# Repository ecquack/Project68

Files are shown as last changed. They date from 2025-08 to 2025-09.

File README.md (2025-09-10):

# Project68

Project68 is a Motorola MC68xxx 16/32 bit single board computer with an 8 bit PIC18 co-processor. 

My goal was to do something interesting with the tube of factory new 68008 CPUs that I've been hoarding for 25 years, 
so I have designed a useful self contained 68K computer using a minumum number of components and special tools.

The system connects directly to a monitor and keyboard and does not require a host computer.

This project is at an early stage of development, but it is intended to run uCLinux 4.4.

Special thanks to [*crmaykish*](https://github.com/crmaykish), creator of the [Mackerel-68K](https://github.com/crmaykish/mackerel-68k) project.

## Project68 features

- MC68008FN8 CPU clocked at 7.16 mHz
- 4 megabytes of SRAM
- Optional overclocking to 14.31818 mHz
- PIC18F87J11 co-processor clocked at 14.31818 mHz (57.27 mHz internal w/4X PLL)
- 80x25 character monochrome ASCII video display (NTSC composite video)
- PS/2 keyboard interface
- TTL/USB serial port
- micro-SD card socket
- Audio Speaker for ASCII “bell” sound
- **No PAL/GAL/CPLD/FPGA programmable logic required**
- Only two LVTTL parts required.
- Expansion ports for a dual serial card and a non-volatile RTC

## OPERATING REQUIREMENTS

- TV or Monitor with composite video input (NTSC)
- PS/2 keyboard
- 5V 1A power supply with USB-C cable (phone charger)
- SD card with uCLinux image

## CPU

The CPU is the 8 bit external bus version of the 68K, the MC68008FN8. It comes in the larger 52 pin PLCC package which can address up to 4 megabytes of memory. The CPU is socketed on the board so that you can use an automated assembly service such as JLC PCB or PCBWAY for all the soldering if you prefer. This is a 16/32 bit CPU internally with a narrow external bus which allows using byte wide external memories.

The parts I have are rated at 8mHz, but 10mHz parts are also available (MC68000FN10). In order to provide an NTSC video clock, the processor runs at ~7.16mHz. Either speed part can (usually) be successfully overclocked to ~14.318mHz without issue. An overclocking jumper is provided if you feel the need for speed.

## MEMORY

The system has four megabytes of memory. It uses a single 32 megabit 4Mx8 55ns SRAM chip. This fills the *entire* available address space with SRAM. There is no separate FLASH, EPROM, or ROM memory, no address decoding of any kind,  no special address hardware at reset, and no traditional memory mapped I/O. Just an unbroken sea of RAM from 0-0x3FFFFF and a simple _DTACK generator. 

The SRAM part is a fairly pricey Renesas RMLV3216AGSA-5S2 sourced from Digikey. You can also use the pin compatible Alliance AS6C6416-55TIN from Mouser which is a 64 megabit part, which is actually cheaper, but you will only be utilizing half the memory.

The memory and the PIC18 run at 3.3 volts (there is an LDO regulator on the board). The 5 volt MC68008  has a logic high level of 2.4 volts, which might be safe to use with these parts. I may end up using level shifters, but they eat 20 nanoseconds from the bus cycle. Stay tuned for my experimental results.

## CO-PROCESSSOR

The PIC18F87J11 microcontroller comes in an 80 pin TQFP package. This part was chosen because it has enough GPIO pins to emulate the entire MC68008 bus. It has 128K of FLASH memory, and just under 4K of on chip SRAM.

**The PIC18 co-processor provides all the main processor’s I/O using soft-DMA.** When it is time to transfer data to or from the processor, the co-processor requests the bus from the 68008. When the bus is granted, it uses bit-banging DMA to read and write the SRAM. A few specific addresses in the memory space are designated as I/O command and status registers and are interpreted as such by the co-processor to provide low level BIOS functions for the console, serial port, and SD card. 

At power up the co-processor asserts _HALT and _RESET and then copies up to 64K of BIOS into the SRAM from the upper half of FLASH memory that’s built into the PIC18. It then releases the 68K bus and the MC68008 starts.

## VIDEO DISPLAY

**The co-processor is also responsible for generating the 80x25 video display.** This is done with a *really* tight  horizontal sync interrupt handler written in assembly language. It uses an interleaved character FLASH lookup table with an 8x8 pixel font. One EUSART on the PIC18 is used as a video shift register (nice!), which makes it possible to clock pixels out once per instruction cycle.

Roughly half of the PIC18's SRAM (2K) is dedicated to the video display.

The physical video interface consists of two output pins and a two resistor network that is connected to an RCA jack. One pin is the output of the synchronous serial transmitter, and the other is the software generated sync line, used for both horizontal and vertical sync.

The video display is not interlaced and does not include a colorburst. The 8x8 ROM font consists of the standard printable ASCII characters (codes 32-126), plus a number of special characters (codes 0-31 and 127). The upper 128 characters are reverse video of the lower 128 characters, which is used to generate the cursor. There are no fancy effects like blink, underscore, or dim. There are no code page 437 special characters.

Most of the co-processor's time is spent generating video. There is a short horizontal blanking period at the end of each line, and there is a longer vertical blanking interval at the end of each video field during which the processor is free to perform other tasks. All video generation (and PS/2 keyboard processing) takes place inside the interrupt handler.

Note that it should be possible to run a PAL monitor instead of NTSC by simply adjusting the timing #DEFINE statements in the beginning of *80columnvideo.h*.
I do not have a monitor that accepts PAL video to test this with.

## PS/2 INTERFACE

The system uses the PIC18 MSSP (synchronous serial port) in slave mode with an assembly language interrupt handler to interface to the PS/2 keyboard. 
The interrupt handler runs during horizontal blanking, and always takes the same number of clock cycles to run, no matter which code path is taken, to avoid disturbing the video output. 

When characters arrive on the PS/2 keyboard or serial port, the co-processor requests the bus, and stores the received characters into a software FIFO in SRAM.

## SD CARD

The SD card socket is connected to the PIC18 over the shared SPI bus. 512 bytes of PIC18 SRAM is reserved to store a single block of data to/from the SD card. 

## BIOS

The BIOS provides a few functions to access the console, the serial port, and the SD card. It also loads and starts Linux from the SD card. Additional functions could be added, for example, to copy the entire screen buffer to and from memory, give control over the PWM audio output beyond the fixed "beep", or to support additional SPI devices such as a non-volatile real time clock. 

## TIMER INTERRUPT

The vertical blanking signal serves as a periodic timer interrupt (60 hertz) to the 68008. This is used by the BIOS for communication and by the Linux kernel for timekeeping and task switching. 

## USB/TTL SERIAL PORT

A CH340N provides a very basic serial port connection to a USB host system. The USB C connector also provides power to the board. There is also a header with jumpers that allow the TTL serial lines to be disconnected from the USB chip and used directly. 

## EXPANSION PORTS

There are two main expansion ports. Each has power, SPI bus, it's own SPI chip select, it's own interrupt line, and two GPIO pins. My intention is to use an SPI DUAL UART on one port and an SPI RTC on the other. Supporting these will require additions to the BIOS. The interrupt line and the chip select can be used as GPIOs if the SPI bus is not used, but MISO, MOSI, and SCLK are shared with the SD card socket and cannot be reassigned.

There is also a third expansion port which brings out the three unused PIC18 GPIO pins, power, and ground. Two of these pins are on port B and can be used as interrupt sources.

## ICSP PORT

For programming the PIC MCU, this 6 pin connector contains PGD, PGC, _MCLR, +5V, and GND.

## PERFORMANCE NOTES

The current system was designed to see how simply a complete 68K computer system could be made, and it uses a minimum number of parts for a system that has its own video and keyboard interfaces. By adding just a few chips you can dramatically increase the performance of the system.

For higher overall system performance you could use a second smaller PIC18 (such as a PIC18F26K22) dedicated to generating video. Right now there is an I/O bottleneck because I/O operations are only performed during video blanking.

A decoded address that causes an interrupt on the PIC18 would eliminate the need for the PIC18 to poll the MC68008's memory. Again, this would increase performance but it would add chips to the design and eat into the memory address space. Two 74HCT30s and a 74HCT00 would suffice, and would eat only 64 bytes from the memory map. 

## BUILD REQUIREMENTS
 
- PIC programmer for initial programming (you can build a very simple bit-banging programmer using a repurposed Arduino)
- Computer system with MicroSD card interface for preparing the SD card.
- CCS PICC C Compiler (optional - pre-built binaries are available)*
- X86 Linux system (optional - a pre-built binary is available)
- KiCAD (optional - Gerber files are provided)

*note that there is a 45 day free trial of this compiler.

## Pre-assembled boards

I started out with a tube full of sixteen 68008 parts that I got from a Motorola rep back in the '90s. I'm keeping a few chips for myself and my friends, but 
I may have a few pre-assembled boards complete with CPUs and SD cards for sale at some point. 

Note that the MC68008FN is no longer in production, but at this time (August, 2025) it is not difficult to find them on eBay for around USD$30 with shipping. 

## PROJECT STATUS

The schematic capture and layout of the first version is complete. I'll order the blank boards and stencil from JLCPCB next.

I wrote the PIC18 80 column video code and the PS/2 keyboard handler code back in 2010 and posted them to the CCS C compiler forum. They were tested on a single sided PIC18F26J11 board that I milled on my CNC machine back in the day.

Once the layout is complete I plan to have a pair of assembled boards made for my by JLCPCB.

After that, the next debugging steps are:

0. Blink the LED
1. Get the video display running
2. test the keyboard port
3. bit-bang the memory interface to read and write from the SRAM
4. load a small test program into the 68K and start it
5. read and write a block from the SD card

Then comes the work of writing the BIOS and building the linux image.

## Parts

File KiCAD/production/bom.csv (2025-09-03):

Designator | Footprint | Quantity | Value | LCSC Part #
BZ1 | MURATA | 1 | Buzzer
C2 | 1206 | 1 | 10uF tantalum
D1 | 1206 | 1 | LED
IC1 | PLCC52-S | 1 | MC68008FN
J1 | CUI_RCJ-044 | 1 | RCJ-044
J10 | PinHeader_1x10_P2.54mm_Vertical | 1 | RTC_OPTION
J11 | PinHeader_1x10_P2.54mm_Vertical | 1 | SERIAL_OPTION
J2 | CUI_MD-60S | 1 | MD-60S
J3 | microSD_HC_Molex_47219-2001 | 1 | Micro_SD_Card
J4 | PinHeader_1x03_P2.54mm_Vertical | 1 | Overclock jumper
J5 | USB_C_Receptacle_GCT_USB4105-xx-A_16P_TopMnt_Horizontal | 1 | USB_C_Receptacle_USB2.0_14P
J6 | PinHeader_1x02_P2.54mm_Vertical | 1 | POWER INPUT
J8 | PinHeader_1x08_P2.54mm_Vertical | 1 | Conn_01x08_Pin
J9 | PinHeader_1x06_P2.54mm_Vertical | 1 | ICSP
Q1 | SOT-23-3 | 1 | NPN
R1 | 1206 | 1 | 330
R10, R3, R9 | 1206 | 3 | 1K
R2 | 1206 | 1 | 680
R4, R5, R6, R7 | 1206 | 4 | 5K1
R8 | 1206 | 1 | 220
U11 | QFP50P1400X1400X120-80N | 1 | PIC18F87J11T-I_PT
U2 | TSOP-I-48_18.4x12mm_P0.5mm | 1 | ~
U3 | SOIC-14_3.9x8.7mm_P1.27mm | 1 | 74LV00
U4 | SOIC-14_3.9x8.7mm_P1.27mm | 1 | 74LV74
U5 | SOT-223-3_TabPin2 | 1 | AMS1117-3.3
U6 | SOP-8_3.9x4.9mm_P1.27mm | 1 | CH340N
Y1 | Oscillator_DIP-14 | 1 | OCXO-14

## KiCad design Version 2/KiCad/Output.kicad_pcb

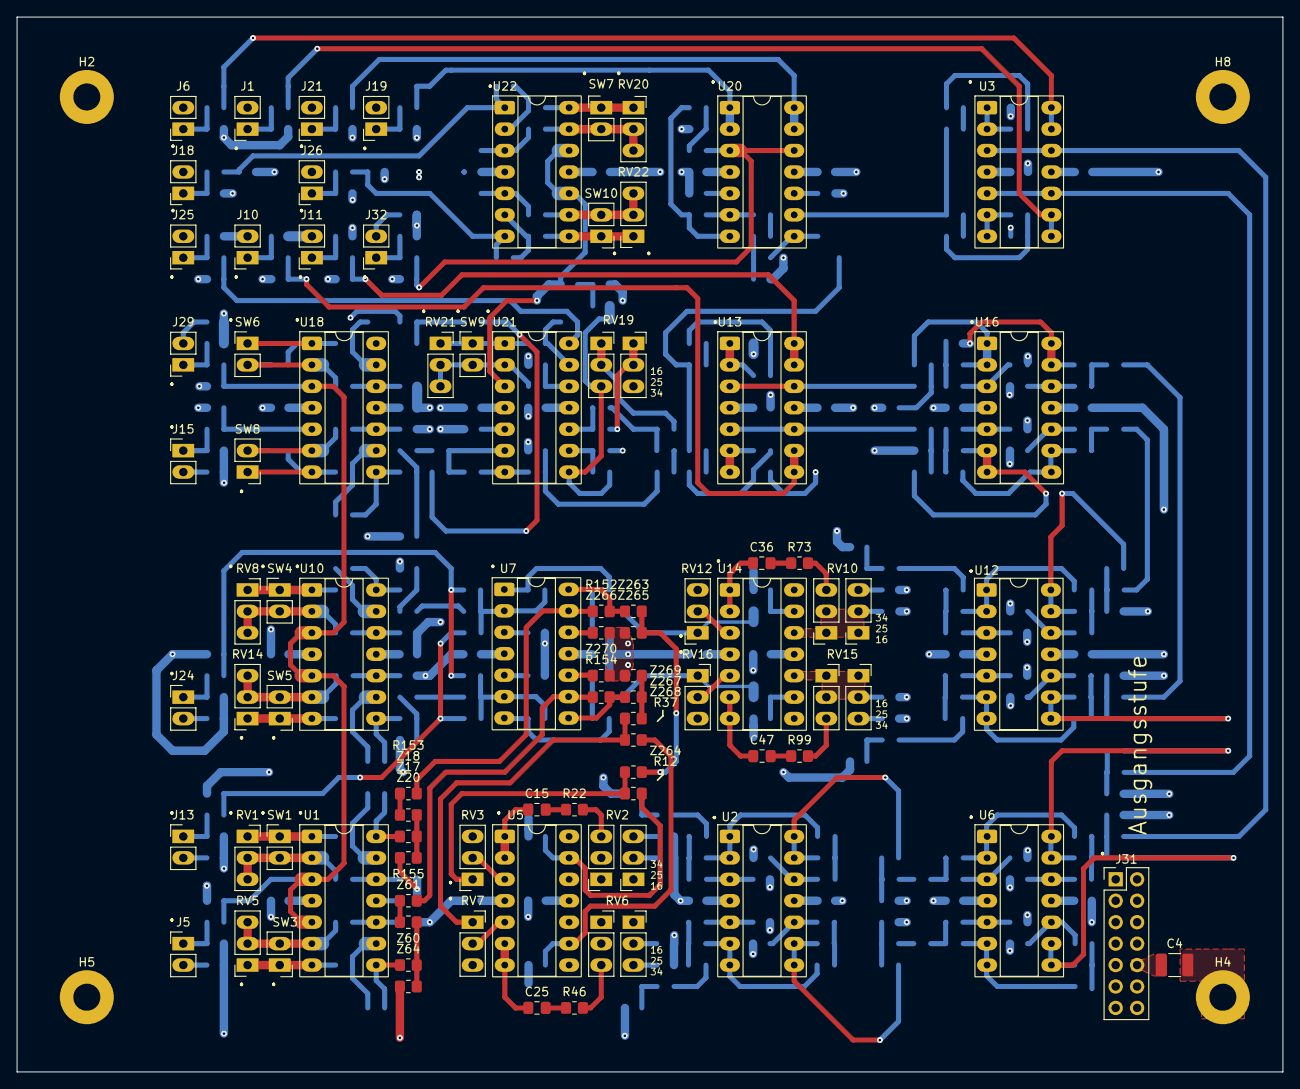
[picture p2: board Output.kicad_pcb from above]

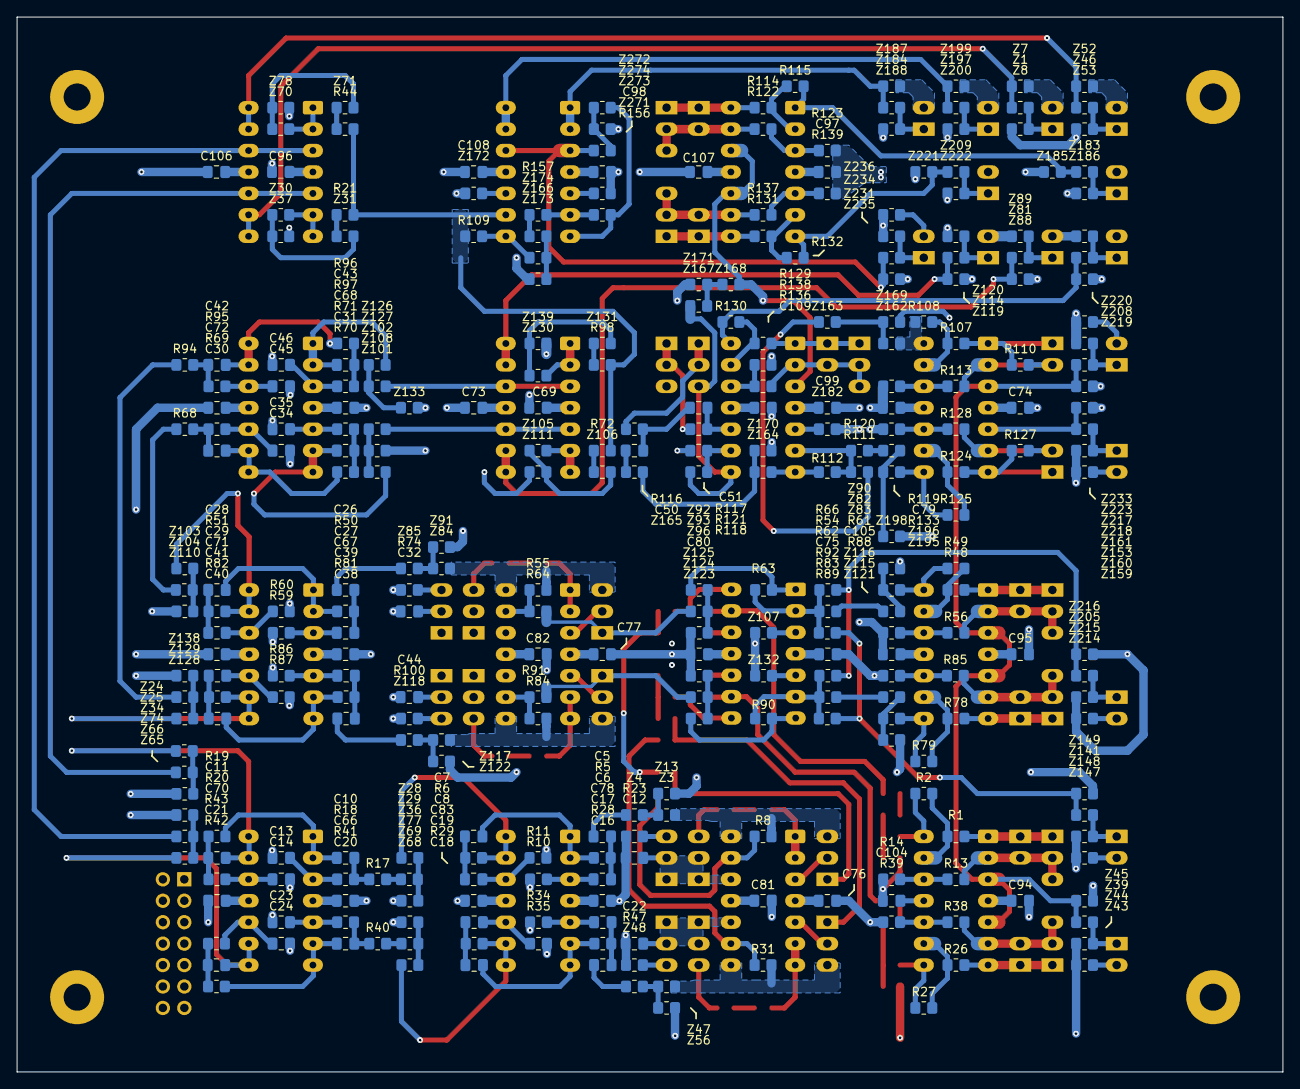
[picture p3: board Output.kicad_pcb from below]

Board: 4 copper layers, 150.0 x 125.0 mm, 393 parts (304 on the bottom side), 253 nets.

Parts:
C4: 10n; C_1210_3225Metric_Pad1.33x2.70mm_HandSolder
C5, C6, C7, C8, C10, C11, C13, C14, C16, C17, C18, C19, C20, C21, C23, C24, C26, C27, C28, C29, C30, C31, C34, C35, C38, C39, C40, C41, C42, C43, C45, C46: 130n; C_0805_2012Metric_Pad1.18x1.45mm_HandSolder
C12, C22, C32, C44: 470p; C_0805_2012Metric_Pad1.18x1.45mm_HandSolder
C15, C25, C36, C47: 3n; C_0805_2012Metric_Pad1.18x1.45mm_HandSolder
C50, C51: 6n8; C_0805_2012Metric_Pad1.18x1.45mm_HandSolder
C66, C67, C68, C69, C70, C71, C72, C73, C74, C75, C76, C77, C78, C79, C80, C81, C82, C83, C94, C95, C96, C97, C98, C99, C104, C105, C106, C107, C108, C109: 100n; C_0805_2012Metric_Pad1.18x1.45mm_HandSolder
H2, H5, H8: MountingHole; MountingHole_3.2mm_M3_Pad
H4: MountingHole_Pad; MountingHole_3.2mm_M3_Pad
J1: Bass_Out; PinSocket_1x02_P2.54mm_Vertical_LongPads
J5: Phono/Line_In; PinHeader_1x02_P2.54mm_Vertical_LongPads
J6: Kick_Out; PinSocket_1x02_P2.54mm_Vertical_LongPads
J10: Mid_Out; PinSocket_1x02_P2.54mm_Vertical_LongPads
J11: High_Out; PinSocket_1x02_P2.54mm_Vertical_LongPads
J13, J15, J24: Mic_Effekt_In; PinHeader_1x02_P2.54mm_Vertical_LongPads
J18: AUX_Send_1; PinSocket_1x02_P2.54mm_Vertical_LongPads
J19: Line_Out_L; PinSocket_1x02_P2.54mm_Vertical_LongPads
J21: Line_Out_R; PinSocket_1x02_P2.54mm_Vertical_LongPads
J25: AUX_Send_3; PinSocket_1x02_P2.54mm_Vertical_LongPads
J26: AUX_Send_2; PinSocket_1x02_P2.54mm_Vertical_LongPads
J29, J32: Pegel_Out; PinSocket_1x02_P2.54mm_Vertical_LongPads
J31: Conn_02x07_Odd_Even; PinHeader_2x07_P2.54mm_Vertical
R1, R26, R48, R78, R114, R129, R131: 4k7; R_0805_2012Metric_Pad1.20x1.40mm_HandSolder
R2, R21, R27, R44, R49, R54, R62, R63, R66, R72, R79, R83, R89, R90, R92, R98, R107, R108, R109, R111, R112, R115, R116, R117, R118, R120, R121, R124, R125, R130, R132, R152, R153, R154, R155, R156, R157: 10k; R_0805_2012Metric_Pad1.20x1.40mm_HandSolder
R5, R6, R10, R11, R22, R23, R28, R29, R34, R35, R46, R47, R50, R51, R59, R60, R73, R74, R81, R82, R86, R87, R99, R100: 6k8; R_0805_2012Metric_Pad1.20x1.40mm_HandSolder
R8, R12, R17, R18, R19, R20, R31, R37, R40, R41, R42, R43, R55, R64, R68, R69, R70, R71, R84, R91, R94, R95, R96, R97: 22k; R_0805_2012Metric_Pad1.20x1.40mm_HandSolder
R13, R38, R56, R85, R122, R136, R137: 470R; R_0805_2012Metric_Pad1.20x1.40mm_HandSolder
R14, R39, R61, R88, R123, R138, R139: 1k; R_0805_2012Metric_Pad1.20x1.40mm_HandSolder
R110, R113, R119, R127, R128, R133: 5k; R_0805_2012Metric_Pad1.20x1.40mm_HandSolder
RV1, RV5, RV8, RV14, RV20, RV21, RV22: 50k log; PinSocket_1x03_P2.54mm_Vertical_LongPads
RV2, RV10: 220k log; PinSocket_2x03_P2.54mm_Vertical_LongPads_Mirrored
RV3, RV7, RV12, RV16: 47k lin; PinSocket_1x03_P2.54mm_Vertical_LongPads
RV6, RV15, RV19: 220k log; PinSocket_2x03_P2.54mm_Vertical_LongPads
SW1, SW3, SW4, SW5, SW6, SW7, SW8, SW9, SW10: SW_SPDT; PinHeader_1x02_P2.54mm_Vertical_LongPads
U1, U2, U3, U5, U6, U7, U10, U12, U13, U14, U16, U18, U20, U21, U22: TL074; DIP-14_W7.62mm_Socket_LongPads
Z1, Z3, Z4, Z7, Z8, Z13, Z17, Z18, Z20, Z24, Z25, Z28, Z29, Z30, Z31, Z34, Z36, Z37, Z39, Z43, Z44, Z45, Z46, Z47, Z48, Z52, Z53, Z56, Z60, Z61, Z64, Z65, Z66, Z68, Z69, Z70, Z71, Z74, Z77, Z78, Z81, Z82, Z83, Z84, Z85, Z88, Z89, Z90, Z91, Z92, Z93, Z96, Z101, Z102, Z103, Z104, Z105, Z106, Z107, Z108, Z110, Z111, Z114, Z115, Z116, Z117, Z118, Z119, Z120, Z121, Z122, Z123, Z124, Z125, Z126, Z127, Z128, Z129, Z130, Z131, Z132, Z133, Z138, Z139, Z141, Z147, Z148, Z149, Z153, Z159, Z160, Z161, Z162, Z163, Z164, Z165, Z166, Z167, Z168, Z169, Z170, Z171, Z172, Z173, Z174, Z182, Z183, Z184, Z185, Z186, Z187, Z188, Z195, Z196, Z197, Z198, Z199, Z200, Z205, Z208, Z209, Z214, Z215, Z216, Z217, Z218, Z219, Z220, Z221, Z222, Z223, Z231, Z233, Z234, Z235, Z236, Z263, Z264, Z265, Z266, Z267, Z268, Z269, Z270, Z271, Z272, Z273, Z274: R_0805_2012Metric_Pad1.20x1.40mm_HandSolder

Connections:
9V_GND_O: J31.1, J31.2, J31.3, J31.4
+9V_O: J31.5, J31.6
+15V_O: C66.2, C67.2, C68.2, C69.2, C74.2, C75.2, C76.2, C77.2, C78.2, C94.2, C95.2, C96.2, C97.2, C98.2, C99.2, J31.13, J31.14, U1.4 (V+), U2.4 (V+), U3.4 (V+), U5.4 (V+), U6.4 (V+), U7.4 (V+), U10.4 (V+), U12.4 (V+), U13.4 (V+), U14.4 (V+), U16.4 (V+), U18.4 (V+), U20.4 (V+), U21.4 (V+), U22.4 (V+)
-15V_O: C70.2, C71.2, C72.2, C73.2, C79.2, C80.2, C81.2, C82.2, C83.2, C104.2, C105.2, C106.2, C107.2, C108.2, C109.2, J31.7, J31.8, U1.11 (V-), U2.11 (V-), U3.11 (V-), U5.11 (V-), U6.11 (V-), U7.11 (V-), U10.11 (V-), U12.11 (V-), U13.11 (V-), U14.11 (V-), U16.11 (V-), U18.11 (V-), U20.11 (V-), U21.11 (V-), U22.11 (V-)
GND_O: C4.2, C12.2, C13.1, C14.1, C22.2, C23.1, C24.1, C32.2, C34.1, C35.1, C44.2, C45.1, C46.1, C66.1, C67.1, C68.1, C69.1, C70.1, C71.1, C72.1, C73.1, C74.1, C75.1, C76.1, C77.1, C78.1, C79.1, C80.1, C81.1, C82.1, C83.1, C94.1, C95.1, C96.1, C97.1, C98.1, C99.1, C104.1, C105.1, C106.1, C107.1, C108.1, C109.1, J1.2, J6.2, J10.2, J11.2, J18.2, J19.2, J21.2, J25.2, J26.2, J31.9, J31.10, J31.11, J31.12, R10.1, R11.1, R14.1, R23.1, R34.1, R35.1, R39.1, R47.1, R59.1, R60.1, R61.1, R74.1, R86.1, R87.1, R88.1, R100.1, R119.2, R121.2, R123.2, R133.2, R138.2, R139.2, RV19.4, Z7.2, Z8.2, Z13.2, Z20.2, Z34.2, Z36.2, Z37.2, Z43.2, Z44.2, Z45.2, Z52.2, Z53.2, Z56.2, Z64.2, Z74.2, Z77.2, Z78.2, Z88.2, Z89.2, Z90.2, Z91.2, Z96.2, Z107.2, Z108.2, Z110.2, Z111.2, Z119.2, Z120.2, Z121.2, Z122.2, Z125.2, Z132.2, Z133.2, Z138.2, Z139.2, Z147.2, Z148.2, Z149.2, Z159.2, Z160.2, Z161.2, Z169.2, Z170.2, Z171.2, Z172.2, Z173.2, Z182.2, Z185.2, Z186.2, Z187.2, Z188.2, Z198.2, Z199.2, Z200.2, Z214.2, Z215.2, Z216.2, Z218.2, Z219.2, Z220.2, Z221.2, Z222.2, Z223.2, Z233.2, Z234.2, Z235.2, Z236.2, Z265.2, Z266.2, Z269.2, Z270.2, Z271.2, Z274.2
unnamed: C4.1, H4.1
unnamed: C5.1, Z4.2
unnamed: C5.2, C6.1, R5.1
unnamed: C7.2, C8.1, R6.1
unnamed: C10.1, R17.2, R18.1
unnamed: C11.1, R19.2, R20.1
unnamed: C15.1, R22.1
unnamed: C16.1, Z48.2
unnamed: C16.2, C17.1, R28.1
unnamed: C18.2, C19.1, R29.1
unnamed: C20.1, R40.2, R41.1
unnamed: C21.1, R42.2, R43.1
unnamed: C25.1, R46.1
unnamed: C26.1, Z85.2
unnamed: C26.2, C27.1, R50.1
unnamed: C28.2, C29.1, R51.1
unnamed: C30.1, R68.2, R69.1
unnamed: C31.1, R70.2, R71.1
unnamed: C36.1, R73.1
unnamed: C38.1, Z118.2
unnamed: C38.2, C39.1, R81.1
unnamed: C40.2, C41.1, R82.1
unnamed: C42.1, R94.2, R95.1
unnamed: C43.1, R96.2, R97.1
unnamed: C47.1, R99.1
unnamed: C50.1, C51.2, R116.1
unnamed: C50.2, Z165.2
unnamed: J1.1, Z1.2, Z8.1
unnamed: J5.1, Z39.1, Z44.1
unnamed: J5.2, Z43.1
unnamed: J6.1, Z46.2, Z53.1
unnamed: J10.1, Z81.2, Z89.1
unnamed: J11.1, Z114.2, Z120.1
unnamed: J13.1, Z141.1, Z148.1
unnamed: J13.2, Z147.1
unnamed: J15.1, Z153.1, Z160.1
unnamed: J15.2, Z159.1
unnamed: J18.1, Z183.2, Z186.1
unnamed: J19.1, Z184.2, Z188.1
unnamed: J21.1, Z197.2, Z200.1
unnamed: J24.1, Z205.1, Z215.1
unnamed: J24.2, Z214.1
unnamed: J25.1, Z208.2, Z220.1
unnamed: J26.1, Z209.2, Z222.1
unnamed: J29.1, Z217.2, Z223.1
unnamed: J29.2, Z233.1
unnamed: J32.1, Z231.1, Z234.1
unnamed: J32.2, Z236.1
unnamed: R2.2, U1.14, Z17.1
unnamed: R8.2, RV3.3, U5.14, Z3.1
unnamed: R12.1, RV3.1, Z264.2
unnamed: R17.1, Z29.2
unnamed: R21.1, Z31.2
unnamed: R22.2, RV2.3
unnamed: R23.2, RV2.4
unnamed: R27.2, U1.8, Z60.1
unnamed: R31.2, RV7.3, U5.8, Z47.1
unnamed: R37.1, RV7.1, Z268.2
unnamed: R40.1, Z69.2
unnamed: R44.1, Z71.2
unnamed: R46.2, RV6.3
unnamed: R47.2, RV6.4
unnamed: R49.2, U10.14, Z82.1
unnamed: R54.1, Z83.2
unnamed: R55.2, RV12.3, U14.14, Z84.1
unnamed: R62.1, R89.1, Z141.2, Z149.1
unnamed: R63.2, U7.1, Z92.1
unnamed: R64.1, RV12.1, Z93.2
unnamed: R66.1, R92.1, Z205.2, Z216.1
unnamed: R68.1, Z104.2
unnamed: R72.1, Z106.2
unnamed: R73.2, RV10.3
unnamed: R74.2, RV10.4
unnamed: R79.2, U10.8, Z115.1
unnamed: R83.1, Z116.2
unnamed: R84.2, RV16.3, U14.8, Z117.1
unnamed: R90.2, U7.7, Z123.1
unnamed: R91.1, RV16.1, Z124.2
unnamed: R94.1, Z129.2
unnamed: R98.1, Z131.2
unnamed: R99.2, RV15.3
unnamed: R100.2, RV15.4
unnamed: R108.1, U18.14, Z162.1
unnamed: R109.2, U20.8, Z166.1
unnamed: R111.2, Z163.2
unnamed: R112.1, U21.7, Z164.1
unnamed: R115.1, U22.1, Z183.1, Z185.1
unnamed: R116.2, RV19.1, RV19.2
unnamed: R117.2, RV19.5, RV19.6
unnamed: R118.1, RV19.3, U21.8, Z167.1
unnamed: R120.2, Z196.2
unnamed: R125.1, U18.8, Z195.1
unnamed: R130.1, U21.14, Z208.1, Z219.1
unnamed: R132.1, U22.7, Z209.1, Z221.1
unnamed: R152.2, U7.14, Z263.1
unnamed: R153.1, Z18.2
unnamed: R154.2, U7.8, Z267.1
unnamed: R155.1, Z61.2
unnamed: R156.1, U20.7, Z272.1
unnamed: R157.1, Z174.2
unnamed: R1.1, RV1.1, SW1.1 (A), U1.1
unnamed: R13.1, RV1.2, RV1.3, SW1.2 (B), U1.2 (-)
unnamed: R26.1, RV5.1, SW3.1 (A), U1.7
unnamed: R38.1, RV5.2, RV5.3, SW3.2 (B), U1.6 (-)
unnamed: R48.1, RV8.1, SW4.1 (A), U10.1
unnamed: R56.1, RV8.2, RV8.3, SW4.2 (B), U10.2 (-)
unnamed: R78.1, RV14.1, SW5.1 (A), U10.7
unnamed: R85.1, RV14.2, RV14.3, SW5.2 (B), U10.6 (-)
unnamed: R107.2, R110.1, SW6.1 (A), U18.1
unnamed: R110.2, R113.2, SW6.2 (B), U18.2 (-)
unnamed: R114.2, RV20.1, SW7.1 (A), U22.14
unnamed: R122.2, RV20.2, RV20.3, SW7.2 (B), U22.13 (-)
unnamed: R124.2, R127.1, SW8.1 (A), U18.7
unnamed: R127.2, R128.2, SW8.2 (B), U18.6 (-)
unnamed: R129.2, RV21.1, SW9.1 (A), U21.1
unnamed: R136.2, RV21.2, RV21.3, SW9.2 (B), U21.2 (-)
unnamed: R131.2, RV22.1, SW10.1 (A), U22.8
unnamed: R137.2, RV22.2, RV22.3, SW10.2 (B), U22.9 (-)
unnamed: R38.2, R39.2, U1.10 (+)
unnamed: R26.2, R27.1, U1.9 (-)
unnamed: R13.2, R14.2, U1.12 (+)
unnamed: R1.2, R2.1, U1.13 (-)
unnamed: C6.2, R10.2, U2.3 (+)
unnamed: C7.1, R5.2, U2.1, U2.2 (-)
unnamed: C17.2, R34.2, U2.5 (+)
unnamed: C18.1, R28.2, U2.6 (-), U2.7
unnamed: C19.2, R35.2, U2.10 (+)
unnamed: R29.2, U2.8, U2.9 (-), Z68.1
unnamed: C8.2, R11.2, U2.12 (+)
unnamed: R6.2, U2.13 (-), U2.14, Z28.1
unnamed: U3.3 (+), U3.12 (+), Z66.2
unnamed: U3.1, U3.2 (-), Z70.1
unnamed: U3.5 (+), U3.10 (+), Z25.2
unnamed: U3.6 (-), U3.7, Z30.1
unnamed: U3.8, U3.9 (-), Z1.1, Z7.1
unnamed: U3.13 (-), U3.14, Z46.1, Z52.1
unnamed: RV3.2, U5.3 (+)
unnamed: C15.2, U5.1, U5.2 (-)
unnamed: RV7.2, U5.5 (+)
unnamed: C25.2, U5.6 (-), U5.7
unnamed: C22.1, RV6.1, RV6.2, RV6.5, RV6.6, U5.10 (+)
unnamed: R31.1, R37.2, U5.9 (-)
unnamed: C12.1, RV2.1, RV2.2, RV2.5, RV2.6, U5.12 (+)
unnamed: R8.1, R12.2, U5.13 (-)
unnamed: C13.2, R18.2, U6.3 (+)
unnamed: C10.2, R19.1, U6.1, U6.2 (-)
unnamed: C23.2, R41.2, U6.5 (+)
unnamed: C20.2, R42.1, U6.6 (-), U6.7
unnamed: C24.2, R43.2, U6.10 (+)
unnamed: C21.2, U6.8, U6.9 (-), Z65.1
unnamed: C14.2, R20.2, U6.12 (+)
unnamed: C11.2, U6.13 (-), U6.14, Z24.1
unnamed: U7.3 (+), Z107.1
unnamed: R54.2, R62.2, R63.1, R66.2, U7.2 (-)
unnamed: U7.5 (+), Z132.1
unnamed: R83.2, R89.2, R90.1, R92.2, U7.6 (-)
unnamed: U7.10 (+), Z270.1
unnamed: R154.1, R155.2, U7.9 (-)
unnamed: U7.12 (+), Z266.1
unnamed: R152.1, R153.2, U7.13 (-)
unnamed: U1.3 (+), U1.5 (+), U10.3 (+), U10.5 (+), U18.3 (+), Z39.2, Z45.1, Z217.1, Z218.1
unnamed: R85.2, R88.2, U10.10 (+)
unnamed: R78.2, R79.1, U10.9 (-)
unnamed: R56.2, R61.2, U10.12 (+)
unnamed: R48.2, R49.1, U10.13 (-)
unnamed: C27.2, R59.2, U12.3 (+)
unnamed: C28.1, R50.2, U12.1, U12.2 (-)
unnamed: C39.2, R86.2, U12.5 (+)
unnamed: C40.1, R81.2, U12.6 (-), U12.7
unnamed: C41.2, R87.2, U12.10 (+)
unnamed: R82.2, U12.8, U12.9 (-), Z128.1
unnamed: C29.2, R60.2, U12.12 (+)
unnamed: R51.2, U12.13 (-), U12.14, Z103.1
unnamed: U13.3 (+), U13.12 (+), Z127.2
unnamed: U13.1, U13.2 (-), Z130.1
unnamed: U13.5 (+), U13.10 (+), Z102.2
unnamed: U13.6 (-), U13.7, Z105.1
unnamed: U13.8, U13.9 (-), Z81.1, Z88.1
unnamed: U13.13 (-), U13.14, Z114.1, Z119.1
unnamed: RV12.2, U14.3 (+)
unnamed: C36.2, U14.1, U14.2 (-)
unnamed: RV16.2, U14.5 (+)
unnamed: C47.2, U14.6 (-), U14.7
unnamed: C44.1, RV15.1, RV15.2, RV15.5, RV15.6, U14.10 (+)
unnamed: R84.1, R91.2, U14.9 (-)
unnamed: C32.1, RV10.1, RV10.2, RV10.5, RV10.6, U14.12 (+)
unnamed: R55.1, R64.2, U14.13 (-)
unnamed: C46.2, R97.2, U16.3 (+)
unnamed: C43.2, U16.1, U16.2 (-), Z126.1
unnamed: C35.2, R71.2, U16.5 (+)
unnamed: C31.2, U16.6 (-), U16.7, Z101.1
unnamed: C34.2, R69.2, U16.10 (+)
unnamed: C30.2, R70.1, U16.8, U16.9 (-)
unnamed: C45.2, R95.2, U16.12 (+)
unnamed: C42.2, R96.1, U16.13 (-), U16.14
unnamed: U18.5 (+), Z153.2, Z161.1
unnamed: R128.1, R133.1, U18.10 (+)
unnamed: R124.1, R125.2, U18.9 (-)
unnamed: R113.1, R119.1, U18.12 (+)
unnamed: R107.1, R108.2, U18.13 (-)
unnamed: U20.3 (+), U20.12 (+), Z231.2, Z235.1, Z273.2
unnamed: U20.1, U20.2 (-), Z184.1, Z187.1
unnamed: U20.5 (+), Z271.1
unnamed: R156.2, R157.2, U20.6 (-)
unnamed: U20.10 (+), Z172.1
unnamed: R21.2, R44.2, R72.2, R98.2, R109.1, U20.9 (-)
unnamed: U20.13 (-), U20.14, Z197.1, Z199.1
unnamed: U21.3 (+), U22.10 (+), U22.12 (+), Z168.2
unnamed: U21.5 (+), Z182.1
unnamed: R111.1, R112.2, R120.1, U21.6 (-)
unnamed: C51.1, R117.1, U21.10 (+)
unnamed: R118.2, R121.1, U21.9 (-)
unnamed: R136.1, R138.1, U21.12 (+)
unnamed: R129.1, R130.2, U21.13 (-)
unnamed: R122.1, R123.1, U22.3 (+)
unnamed: R114.1, R115.2, U22.2 (-)
unnamed: R137.1, R139.1, U22.5 (+)
unnamed: R131.1, R132.2, U22.6 (-)
unnamed: Z3.2, Z4.1, Z13.1
unnamed: Z17.2, Z18.1, Z20.1
unnamed: Z24.2, Z25.1, Z34.1
unnamed: Z28.2, Z29.1, Z36.1
unnamed: Z30.2, Z31.1, Z37.1
unnamed: Z47.2, Z48.1, Z56.1
unnamed: Z60.2, Z61.1, Z64.1
unnamed: Z65.2, Z66.1, Z74.1
unnamed: Z68.2, Z69.1, Z77.1
unnamed: Z70.2, Z71.1, Z78.1
unnamed: Z82.2, Z83.1, Z90.1
unnamed: Z84.2, Z85.1, Z91.1
unnamed: Z92.2, Z93.1, Z96.1
unnamed: Z101.2, Z102.1, Z108.1
unnamed: Z103.2, Z104.1, Z110.1
unnamed: Z105.2, Z106.1, Z111.1
unnamed: Z115.2, Z116.1, Z121.1
unnamed: Z117.2, Z118.1, Z122.1
unnamed: Z123.2, Z124.1, Z125.1
unnamed: Z126.2, Z127.1, Z133.1
unnamed: Z128.2, Z129.1, Z138.1
unnamed: Z130.2, Z131.1, Z139.1
unnamed: Z162.2, Z163.1, Z169.1
unnamed: Z164.2, Z165.1, Z170.1
unnamed: Z166.2, Z173.1, Z174.1
unnamed: Z167.2, Z168.1, Z171.1
unnamed: Z195.2, Z196.1, Z198.1
unnamed: Z263.2, Z264.1, Z265.1
unnamed: Z267.2, Z268.1, Z269.1
unnamed: Z272.2, Z273.1, Z274.1

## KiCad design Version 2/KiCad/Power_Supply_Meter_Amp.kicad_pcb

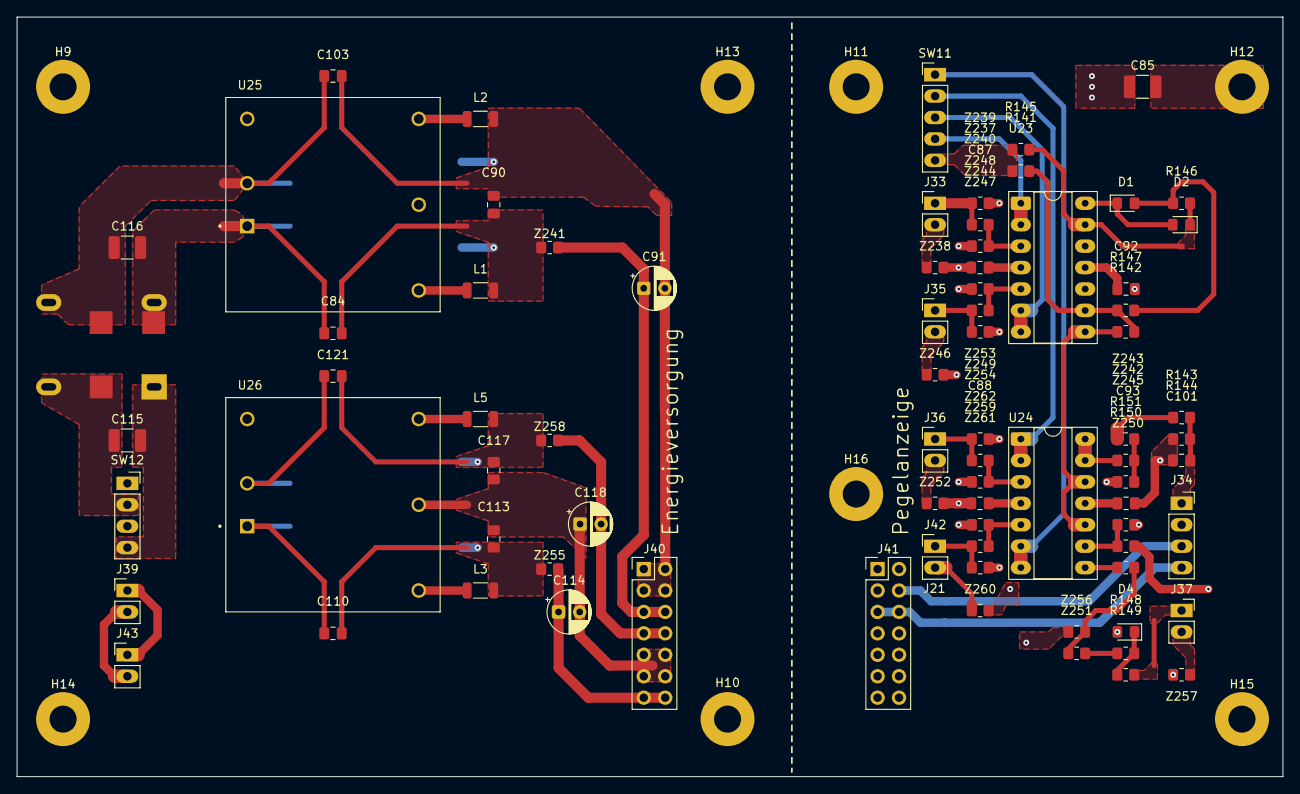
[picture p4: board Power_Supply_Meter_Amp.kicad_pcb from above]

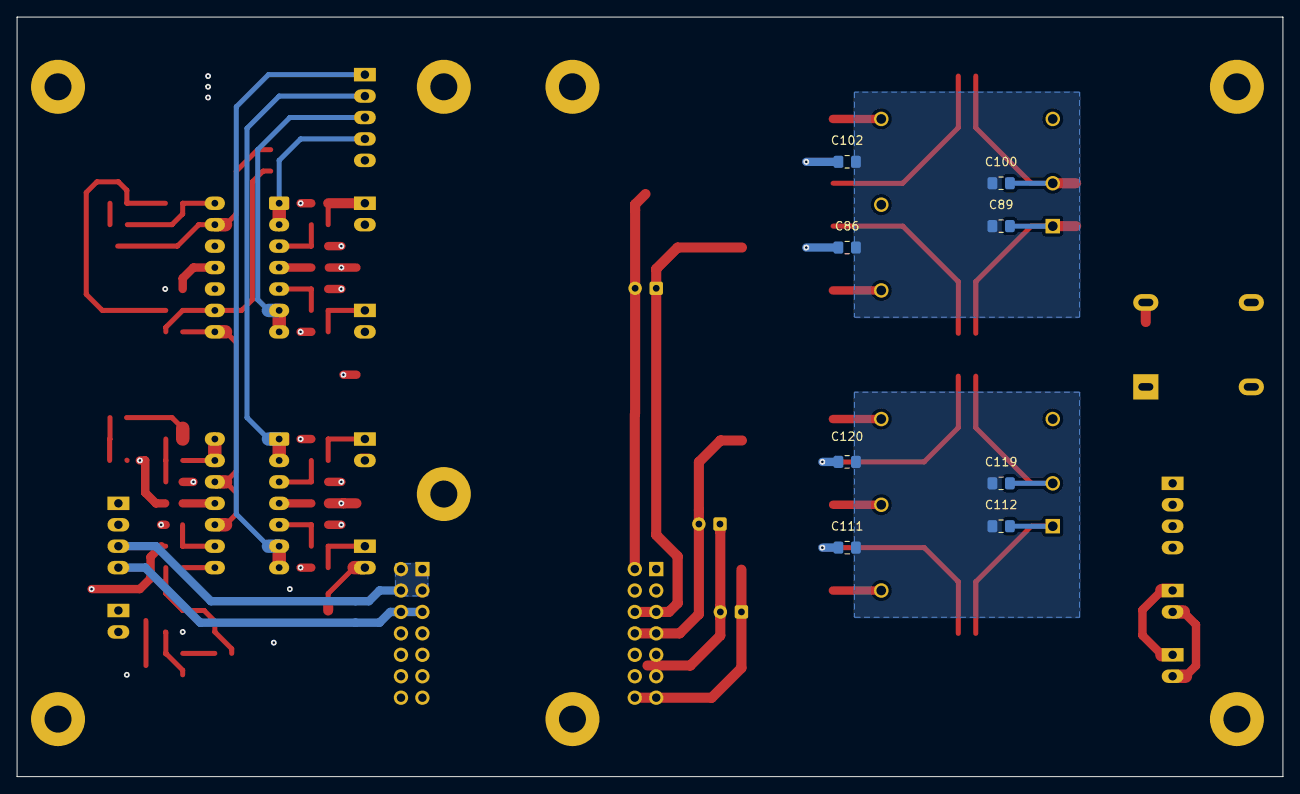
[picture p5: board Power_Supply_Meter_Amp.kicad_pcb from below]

Board: 4 copper layers, 150.0 x 90.0 mm, 95 parts (8 on the bottom side), 59 nets.

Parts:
C84, C103, C110, C121: 470p; C_0805_2012Metric_Pad1.18x1.45mm_HandSolder
C85: 10n; C_1210_3225Metric_Pad1.33x2.70mm_HandSolder
C86, C102, C111, C120: 1n; C_0805_2012Metric_Pad1.18x1.45mm_HandSolder
C87, C88, C90, C92, C93, C113, C117: 100n; C_0805_2012Metric_Pad1.18x1.45mm_HandSolder
C89, C100, C112, C119: 10n; C_0805_2012Metric_Pad1.18x1.45mm_HandSolder
C91, C114, C118: 10u; CP_Radial_D5.0mm_P2.50mm
C101: 4u7; C_0805_2012Metric_Pad1.18x1.45mm_HandSolder
C115, C116: 10u; C_1210_3225Metric_Pad1.33x2.70mm_HandSolder
D1, D2, D4: D; D_0805_2012Metric_Pad1.15x1.40mm_HandSolder
H9, H10, H11, H13, H14, H15, H16: MountingHole; MountingHole_3.2mm_M3_Pad
H12: MountingHole_Pad; MountingHole_3.2mm_M3_Pad
J33, J35, J36, J42: Pegel_In; PinHeader_1x02_P2.54mm_Vertical_LongPads
J34: VU_Meter_Out; PinSocket_1x04_P2.54mm_Vertical_LongPdas
J37: LED_Out; PinSocket_1x02_P2.54mm_Vertical_LongPads
J39: VCC_IN; PinHeader_1x02_P2.54mm_Vertical_LongPads
J40, J41: Conn_02x07_Odd_Even; PinHeader_2x07_P2.54mm_Vertical
J43: VCC_OUT; PinHeader_1x02_P2.54mm_Vertical_LongPads
L1, L2, L3, L5: Dämpfungsperle, 220 Ohm @ 100MHz, 0.5A; L_1206_3216Metric
L4: WE-SL575
R141: 20k; R_0805_2012Metric_Pad1.20x1.40mm_HandSolder
R142: 80k; R_0805_2012Metric_Pad1.20x1.40mm_HandSolder
R143, R144: 1k8; R_0805_2012Metric_Pad1.20x1.40mm_HandSolder
R145, R146, R149: 1k; R_0805_2012Metric_Pad1.20x1.40mm_HandSolder
R147, R148: 10k; R_0805_2012Metric_Pad1.20x1.40mm_HandSolder
R150: 12k; R_0805_2012Metric_Pad1.20x1.40mm_HandSolder
R151: 3k; R_0805_2012Metric_Pad1.20x1.40mm_HandSolder
SW11: SW_Rotary_1x4; PinHeader_1x05_P2.54mm_Vertical_LongPads
SW12: SW_DPST; PinSocket_1x04_P2.54mm_Vertical_LongPdas
U23, U24: TL074; DIP-14_W7.62mm_Socket_LongPads
U25: REC10K-2409; CONV_REC10K-2409SAW_H2
U26: REC10K-2415; CONV_REC10K-2415DAW_H2
Z237, Z238, Z239, Z240, Z241, Z242, Z243, Z244, Z245, Z246, Z247, Z248, Z249, Z250, Z251, Z252, Z253, Z254, Z255, Z256, Z257, Z258, Z259, Z260, Z261, Z262: R_0805_2012Metric_Pad1.20x1.40mm_HandSolder

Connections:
9V_GND_M: J34.3, J41.1, J41.2, J41.3, J41.4
9V_GND_P: C90.2, C91.2, C102.1, C103.2, J40.1, J40.2, J40.3, J40.4, L2.2
+9V_M: J34.4, J41.5, J41.6
+9V_P: C91.1, J40.5, J40.6, Z241.2
+15V_M: C87.2, C88.2, J41.13, J41.14, R150.1, U23.4 (V+), U24.4 (V+)
+15V_P: C114.1, J40.13, J40.14, Z255.2
-15V_M: C92.2, C93.2, J41.7, J41.8, U23.11 (V-), U24.11 (V-)
-15V_P: C118.2, J40.7, J40.8, Z258.2
/Pegel_Aux_Return: SW11.2, U24.1, U24.2 (-)
/Pegel_Mic_Effekt: SW11.3, U23.6 (-), U23.7
/Pegel_Post: SW11.1, U24.6 (-), U24.7
/Pegel_Pre: SW11.4, U23.1, U23.2 (-)
GND_9V_FILT: C86.1, C89.1, C100.2, C102.2
GND_15V_FILT: C111.1, C112.1, C119.2, C120.2
GND_M: C85.2, C87.1, C88.1, C92.1, C93.1, C101.2, D4.2 (A), J34.2, J41.9, J41.10, J41.11, J41.12, R144.1, R151.1, U23.10 (+), U23.12 (+), Z238.2, Z239.2, Z240.2, Z245.2, Z246.2, Z247.2, Z248.2, Z252.2, Z253.2, Z254.2, Z256.2, Z257.2, Z260.2, Z261.2, Z262.2
GND_P: C113.2, C114.2, C117.1, C118.1, J40.9, J40.10, J40.11, J40.12, U26.5 (COM)
unnamed: C84.2, C86.2, C90.1, L1.2, Z241.1
unnamed: C85.1, H12.1
unnamed: C110.2, C111.2, C113.1, L3.2, Z255.1
unnamed: C115.1, L4.1, SW12.4
unnamed: C115.2, L4.4, SW12.2
unnamed: C117.2, C120.1, C121.2, L5.2, Z258.1
unnamed: D1.2 (A), R146.2, R147.1
unnamed: D1.1 (K), D2.2 (A), U23.14
unnamed: D2.1 (K), R145.2, R146.1, U23.13 (-)
unnamed: D4.1 (K), R148.1, R149.2
unnamed: J33.1, Z237.1, Z239.1
unnamed: J33.2, Z238.1
unnamed: C101.1, J34.1, R143.2, R144.2
unnamed: J35.1, Z244.1, Z247.1
unnamed: J35.2, Z246.1
unnamed: J36.1, Z249.1, Z253.1
unnamed: J36.2, Z252.1
unnamed: J37.1, R149.1
unnamed: J37.2, Z257.1
unnamed: J39.1, J43.1, SW12.3
unnamed: J39.2, J43.2, SW12.1
unnamed: J42.1, Z259.1, Z261.1
unnamed: J42.2, Z260.1
unnamed: R141.1, R145.1, SW11.5
unnamed: R143.1, Z243.2
unnamed: R148.2, Z251.2
unnamed: U23.3 (+), Z237.2, Z240.1
unnamed: U23.5 (+), Z244.2, Z248.1
unnamed: R141.2, R142.1, R147.2, U23.9 (-)
unnamed: U24.8, Z250.1
unnamed: U24.3 (+), Z249.2, Z254.1
unnamed: U24.5 (+), Z259.2, Z262.1
unnamed: R142.2, U23.8, U24.10 (+), U24.12 (+)
unnamed: R150.2, R151.2, U24.9 (-)
unnamed: U24.13 (-), U24.14, Z242.1
unnamed: C84.1, C89.2, C110.1, C112.2, C116.1, L4.2, U25.1 (+VIN), U26.1 (+VIN)
unnamed: L1.1, U25.6 (+VOUT)
unnamed: C100.1, C103.1, C116.2, C119.1, C121.1, L4.3, U25.2 (-VIN), U26.2 (-VIN)
unnamed: L2.1, U25.4 (-VOUT)
unnamed: L3.1, U26.6 (+VOUT)
unnamed: L5.1, U26.4 (-VOUT)
unnamed: Z242.2, Z243.1, Z245.1
unnamed: Z250.2, Z251.1, Z256.1

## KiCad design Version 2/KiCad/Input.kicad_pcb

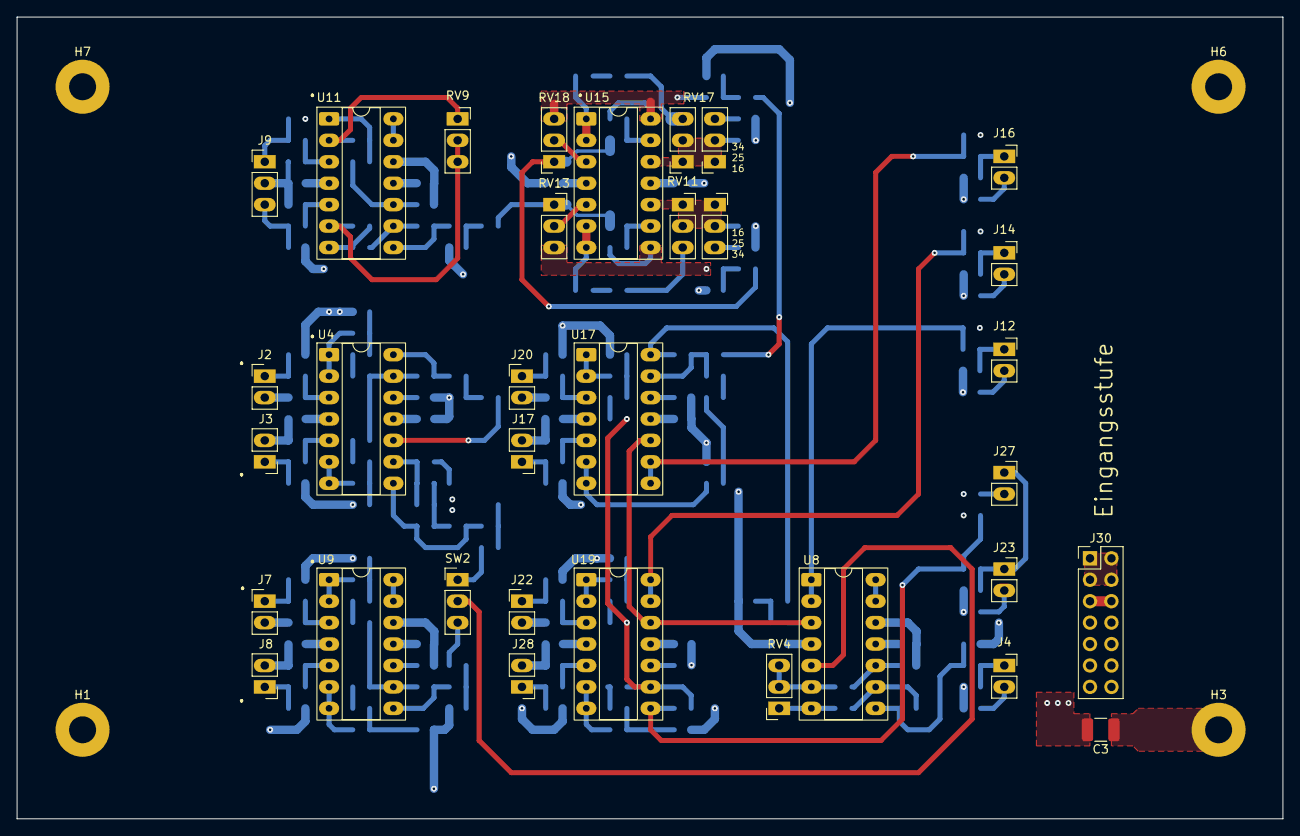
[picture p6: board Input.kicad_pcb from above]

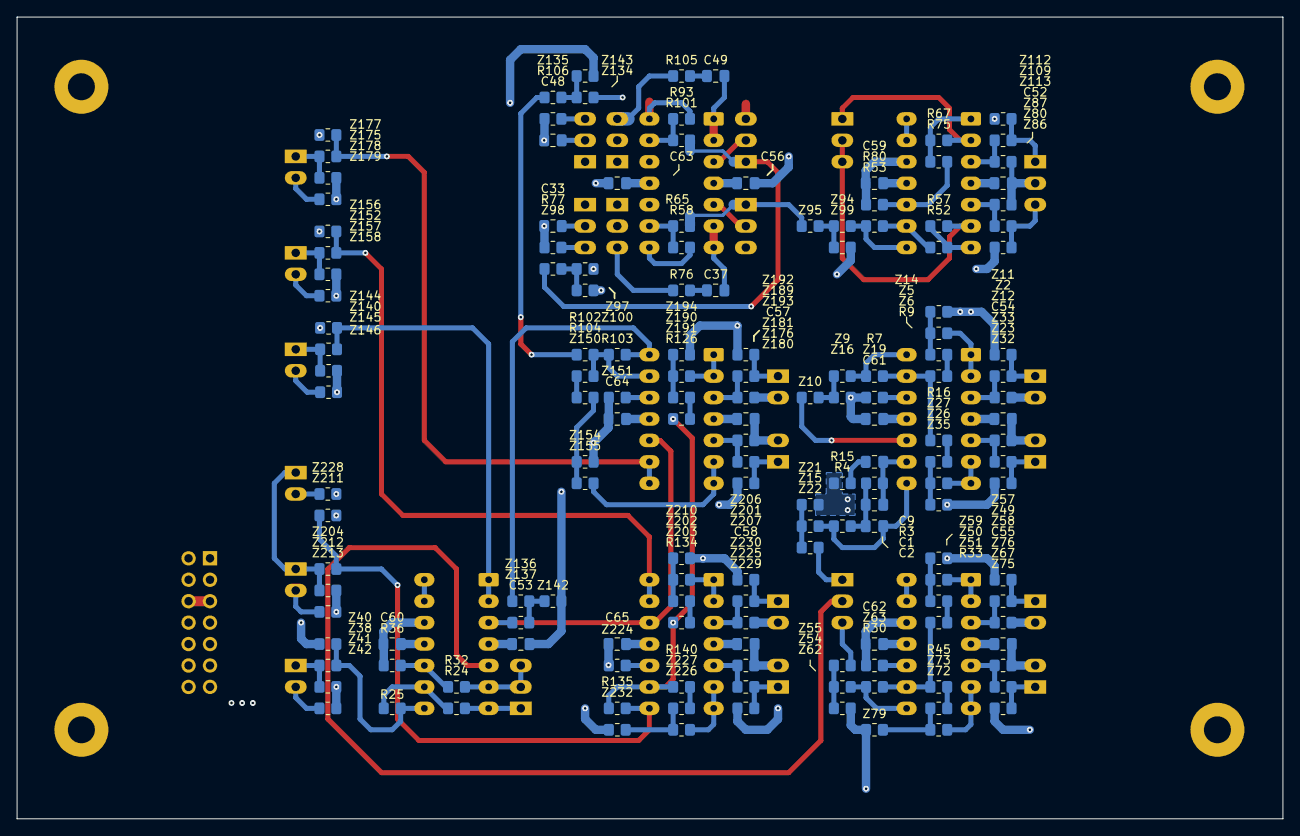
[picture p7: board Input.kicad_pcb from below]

Board: 4 copper layers, 150.0 x 95.0 mm, 190 parts (155 on the bottom side), 126 nets.

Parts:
C1: 2n2; C_0805_2012Metric_Pad1.18x1.45mm_HandSolder
C2: 10n; C_0805_2012Metric_Pad1.18x1.45mm_HandSolder
C3: 10n; C_1210_3225Metric_Pad1.33x2.70mm_HandSolder
C9: 47u; C_0805_2012Metric_Pad1.18x1.45mm_HandSolder
C33, C48: 470p; C_0805_2012Metric_Pad1.18x1.45mm_HandSolder
C37, C49: 3n; C_0805_2012Metric_Pad1.18x1.45mm_HandSolder
C52, C53, C54, C55, C56, C57, C58, C59, C60, C61, C62, C63, C64, C65: 100n; C_0805_2012Metric_Pad1.18x1.45mm_HandSolder
H1, H6, H7: MountingHole; MountingHole_3.2mm_M3_Pad
H3: MountingHole_Pad; MountingHole_3.2mm_M3_Pad
J2: R_Phono_In; PinHeader_1x02_P2.54mm_Vertical_LongPads
J3: L_Phono_In; PinHeader_1x02_P2.54mm_Vertical_LongPads
J4: Phono/Line_Out; PinSocket_1x02_P2.54mm_Vertical_LongPads
J7: R_Line_In; PinHeader_1x02_P2.54mm_Vertical_LongPads
J8: L_Line_In; PinHeader_1x02_P2.54mm_Vertical_LongPads
J9: Mic_In; PinHeader_1x03_P2.54mm_Vertical_LongPads
J12, J14, J16, J23, J27: Mic_Effekt_Out; PinSocket_1x02_P2.54mm_Vertical_LongPads
J17: AUX_RET_1; PinHeader_1x02_P2.54mm_Vertical_LongPads
J20: Effekt_In; PinHeader_1x02_P2.54mm_Vertical_LongPads
J22: AUX_RET_2; PinHeader_1x02_P2.54mm_Vertical_LongPads
J28: AUX_RET_3; PinHeader_1x02_P2.54mm_Vertical_LongPads
J30: Conn_02x07_Odd_Even; PinHeader_2x07_P2.54mm_Vertical
R3: 36k; R_0805_2012Metric_Pad1.20x1.40mm_HandSolder
R4: 390k; R_0805_2012Metric_Pad1.20x1.40mm_HandSolder
R7, R9, R16, R25, R30, R33, R45, R52, R53, R57, R67, R75, R80, R102, R103, R104, R126, R134, R135, R140: 10k; R_0805_2012Metric_Pad1.20x1.40mm_HandSolder
R15, R36: 1k; R_0805_2012Metric_Pad1.20x1.40mm_HandSolder
R24: 4k7; R_0805_2012Metric_Pad1.20x1.40mm_HandSolder
R32: 470R; R_0805_2012Metric_Pad1.20x1.40mm_HandSolder
R58, R65, R93, R101: 22k; R_0805_2012Metric_Pad1.20x1.40mm_HandSolder
R76, R77, R105, R106: 6k8; R_0805_2012Metric_Pad1.20x1.40mm_HandSolder
RV4: 50k log; PinSocket_1x03_P2.54mm_Vertical_LongPads
RV9: 10k lin; PinSocket_1x03_P2.54mm_Vertical_LongPads
RV11: 220k log; PinSocket_2x03_P2.54mm_Vertical_LongPads
RV13, RV18: 47k lin; PinSocket_1x03_P2.54mm_Vertical_LongPads
RV17: 220k log; PinSocket_2x03_P2.54mm_Vertical_LongPads_Mirrored
SW2: SW_SPDT; PinHeader_1x03_P2.54mm_Vertical_LongPads
U4, U8, U9, U11, U15, U17, U19: TL074; DIP-14_W7.62mm_Socket_LongPads
Z2, Z5, Z6, Z9, Z10, Z11, Z12, Z14, Z15, Z16, Z19, Z21, Z22, Z23, Z26, Z27, Z32, Z33, Z35, Z38, Z40, Z41, Z42, Z49, Z50, Z51, Z54, Z55, Z57, Z58, Z59, Z62, Z63, Z67, Z72, Z73, Z75, Z76, Z79, Z80, Z86, Z87, Z94, Z95, Z97, Z98, Z99, Z100, Z109, Z112, Z113, Z134, Z135, Z136, Z137, Z140, Z142, Z143, Z144, Z145, Z146, Z150, Z151, Z152, Z154, Z155, Z156, Z157, Z158, Z175, Z176, Z177, Z178, Z179, Z180, Z181, Z189, Z190, Z191, Z192, Z193, Z194, Z201, Z202, Z203, Z204, Z206, Z207, Z210, Z211, Z212, Z213, Z224, Z225, Z226, Z227, Z228, Z229, Z230, Z232: R_0805_2012Metric_Pad1.20x1.40mm_HandSolder

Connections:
9V_GND_I: J30.1, J30.2, J30.3, J30.4
+9V_I: J30.5, J30.6
+15V_I: C52.1, C53.2, C54.2, C55.2, C56.2, C57.2, C58.2, J30.13, J30.14, U4.4 (V+), U8.4 (V+), U9.4 (V+), U11.4 (V+), U15.4 (V+), U17.4 (V+), U19.4 (V+)
-15V_I: C59.2, C60.2, C61.2, C62.2, C63.2, C64.2, C65.2, J30.7, J30.8, U4.11 (V-), U8.11 (V-), U9.11 (V-), U11.11 (V-), U15.11 (V-), U17.11 (V-), U19.11 (V-)
GND_I: C3.2, C33.2, C48.2, C52.2, C53.1, C54.1, C55.1, C56.1, C57.1, C58.1, C59.1, C60.1, C61.1, C62.1, C63.1, C64.1, C65.1, J2.2, J3.2, J7.2, J8.2, J9.2, J17.2, J20.2, J22.2, J28.2, J30.9, J30.10, J30.11, J30.12, R15.1, R36.1, R77.1, R80.1, R106.1, U8.12 (+), U9.12 (+), U11.12 (+), Z11.2, Z12.2, Z14.2, Z16.2, Z19.2, Z21.2, Z32.2, Z33.2, Z35.2, Z40.2, Z41.2, Z42.2, Z57.2, Z58.2, Z59.2, Z62.2, Z63.2, Z75.2, Z76.2, Z79.2, Z86.2, Z87.2, Z99.2, Z100.2, Z112.2, Z113.2, Z142.2, Z143.1, Z144.2, Z145.2, Z146.2, Z151.2, Z154.2, Z156.2, Z157.2, Z158.2, Z177.2, Z178.2, Z179.2, Z180.2, Z181.2, Z192.2, Z193.2, Z194.2, Z206.2, Z207.2, Z210.2, Z211.2, Z212.2, Z213.2, Z224.2, Z228.2, Z229.2, Z230.2, Z232.2
unnamed: C1.2, C2.1, R3.1, R4.2
unnamed: C2.2, R4.1, U4.8, Z15.1
unnamed: C3.1, H3.1
unnamed: C9.1, R15.2
unnamed: C37.1, R76.1
unnamed: C49.1, R105.1
unnamed: J2.1, Z2.1, Z11.1
unnamed: J3.1, Z23.1, Z32.1
unnamed: J4.1, Z38.2, Z41.1
unnamed: J4.2, Z42.1
unnamed: J7.1, Z49.1, Z57.1
unnamed: J8.1, Z67.1, Z75.1
unnamed: J9.1, Z109.1, Z112.1
unnamed: J9.3, Z80.1, Z86.1
unnamed: J12.1, Z140.2, Z145.1
unnamed: J12.2, Z146.1
unnamed: J14.1, Z152.2, Z157.1
unnamed: J14.2, Z158.1
unnamed: J16.1, Z175.2, Z178.1
unnamed: J16.2, Z179.1
unnamed: J17.1, Z176.1, Z180.1
unnamed: J20.1, Z189.1, Z192.1
unnamed: J22.1, Z201.1, Z206.1
unnamed: J23.1, J27.1, Z204.2, Z212.1
unnamed: J23.2, Z213.1
unnamed: J27.2, Z228.1
unnamed: J28.1, Z225.1, Z229.1
unnamed: R7.2, U4.14, Z9.1
unnamed: R9.1, Z6.2
unnamed: R16.1, Z27.2
unnamed: R24.1, RV4.1, U8.7
unnamed: R25.2, U8.8, Z38.1, Z40.1
unnamed: R30.2, U9.8, Z54.1
unnamed: R33.1, Z51.2
unnamed: R45.1, Z73.2
unnamed: R52.1, R57.2, U11.7
unnamed: R53.1, U11.8, Z94.1
unnamed: R58.2, RV13.3, U15.8, Z97.1
unnamed: R65.1, RV13.1, Z95.2
unnamed: R67.1, R75.1, U11.1
unnamed: R76.2, RV11.3
unnamed: R77.2, RV11.4
unnamed: R93.2, RV18.3, U15.14, Z134.1
unnamed: R101.1, RV18.1, Z98.2
unnamed: R102.1, Z135.2
unnamed: R103.2, U17.14, Z136.1
unnamed: R104.1, Z150.1
unnamed: R105.2, RV17.3
unnamed: R106.2, RV17.4
unnamed: R126.2, Z191.2
unnamed: R134.2, Z203.2
unnamed: R135.1, U19.8, Z204.1, Z211.1
unnamed: R140.2, Z227.2
unnamed: SW2.1 (A), Z22.2
unnamed: SW2.2 (B), U8.5 (+)
unnamed: SW2.3 (C), Z55.2
unnamed: U4.3 (+), Z2.2, Z12.1
unnamed: U4.1, U4.2 (-), Z5.1
unnamed: U4.5 (+), Z23.2, Z33.1
unnamed: U4.6 (-), U4.7, Z26.1
unnamed: U4.10 (+), Z10.2
unnamed: C1.1, C9.2, R3.2, U4.9 (-)
unnamed: U4.12 (+), Z19.1
unnamed: R7.1, R9.2, R16.2, U4.13 (-)
unnamed: U8.1, U8.2 (-), Z140.1, Z144.1
unnamed: R32.1, RV4.2, RV4.3, U8.6 (-)
unnamed: R32.2, R36.2, U8.10 (+)
unnamed: R24.2, R25.1, U8.9 (-)
unnamed: U8.13 (-), U8.14
unnamed: U9.3 (+), Z49.2, Z58.1
unnamed: U9.1, U9.2 (-), Z50.1
unnamed: U9.5 (+), Z67.2, Z76.1
unnamed: U9.6 (-), U9.7, Z72.1
unnamed: U9.10 (+), Z63.1
unnamed: R30.1, R33.2, R45.2, U9.9 (-)
unnamed: U9.13 (-), U9.14
unnamed: U11.3 (+), Z109.2, Z113.1
unnamed: R67.2, RV9.1, U11.2 (-)
unnamed: U11.5 (+), Z80.2, Z87.1
unnamed: R57.1, RV9.2, RV9.3, U11.6 (-)
unnamed: R75.2, R80.2, U11.10 (+)
unnamed: R52.2, R53.2, U11.9 (-)
unnamed: U11.13 (-), U11.14
unnamed: RV18.2, U15.3 (+)
unnamed: C49.2, U15.1, U15.2 (-)
unnamed: RV13.2, U15.5 (+)
unnamed: C37.2, U15.6 (-), U15.7
unnamed: C33.1, RV11.1, RV11.2, RV11.5, RV11.6, U15.10 (+)
unnamed: R58.1, R65.2, U15.9 (-)
unnamed: C48.1, RV17.1, RV17.2, RV17.5, RV17.6, U15.12 (+)
unnamed: R93.1, R101.2, U15.13 (-)
unnamed: U17.3 (+), Z189.2, Z193.1
unnamed: U17.1, U17.2 (-), Z190.1
unnamed: U17.5 (+), Z176.2, Z181.1
unnamed: U17.6 (-), U17.7, Z155.2
unnamed: U8.3 (+), U17.10 (+), U19.12 (+), Z137.2
unnamed: U17.8, U17.9 (-), Z175.1, Z177.1
unnamed: U17.12 (+), Z151.1
unnamed: R102.2, R103.1, R104.2, U17.13 (-)
unnamed: U19.3 (+), Z201.2, Z207.1
unnamed: U19.1, U19.2 (-), Z202.1
unnamed: U19.5 (+), Z225.2, Z230.1
unnamed: U19.6 (-), U19.7, Z226.1
unnamed: U19.10 (+), Z224.1
unnamed: R126.1, R134.1, R135.2, R140.1, U19.9 (-)
unnamed: U19.13 (-), U19.14, Z152.1, Z156.1
unnamed: Z9.2, Z10.1, Z16.1
unnamed: Z5.2, Z6.1, Z14.1
unnamed: Z15.2, Z21.1, Z22.1
unnamed: Z26.2, Z27.1, Z35.1
unnamed: Z50.2, Z51.1, Z59.1
unnamed: Z54.2, Z55.1, Z62.1
unnamed: Z72.2, Z73.1, Z79.1
unnamed: Z94.2, Z95.1, Z99.1
unnamed: Z97.2, Z98.1, Z100.1
unnamed: Z134.2, Z135.1, Z143.2
unnamed: Z136.2, Z137.1, Z142.1
unnamed: Z150.2, Z154.1, Z155.1
unnamed: Z190.2, Z191.1, Z194.1
unnamed: Z202.2, Z203.1, Z210.1
unnamed: Z226.2, Z227.1, Z232.1

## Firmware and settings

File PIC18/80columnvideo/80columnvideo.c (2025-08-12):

/*
      40/80 Column Video Display using a PIC18F26K20.

      Copyright (c) 2010 Erik C. Quackenbush
      Non-commercial distribution permitted.

This version works correctly DOUBLE40 and 80 with white stripe along side
of 80. If we change the HPORCH value from 34 to 30 then the white stripe
goes away but we get a color flash every 22 seconds.

We did not have a color flash yesterday.


CPU Crystal is:
14.318180 mHz which is 4X NTSC colorburst giving 69.84 nanosecond pixels
13.5 mHz which is CCIR-601 square pixels 74.07 nanoseconds
16 mHz which is the maximum clock rate (4X=64mhz) with 62.5 nanosecond pixels

hardware details:

connect the video output to PIN_C2 through a 680 ohm resistor
connect the video output to PIN_C7 through a 330 ohm resistor
run the chip at 3.3 volts
connect an LED to PIN_A5

we're using EUSART as our video shift register.
baud rate divisor is 0 so it outputs one pixel per CPU clock (Fosc/4)
which should be 14.318 mHz or ~70ns

we use timer 2 to generate an interrupt at the beginning of each scan line.
We use a divide by 4 prescaler and set the period register to 227. This
gives us 908 cycles per line. We want to have 910 cycles per line. We can disable the
timer for a single clock cycle (one instruction to turn it off, the following instruction
turns it back on) or two or three in order to get our horizontal sweep frequency just right.
It should be 15.75 khz

we are only generating one field- not a true interlaced signal
we are therefore one line short: 524 lines instead of 525.

*/

//#define KCPU
#define SAVESCRATCH

#ifdef KCPU
#include <18F26K20.H>
#define  HSPLL H4
#else // J CPU
#include <18F26J11.H>
#endif


//#define CRYSTAL28
//#define CRYSTAL13       // 13.5mHz crystal CCIR-601 square pixels
#define CRYSTAL14     // 14.31818 mHz crystal NTSC pixels (4X color burst)
//#define CRYSTAL16     // 16mHz internal oscillator works but the display
                        // is wavy. You really need an HS crystal.

//#define  DOUBLE40       // define DOUBLE40 if you want a 40 column display
                        // comment it out if you want an 80 column display
                        // 40 columns looks good on standard TV sets.
                        // 80 columns looks good on most flat panel TVs.
                        
                        // 40 columns is implemented as a 640 pixel display
                        // that creates double wide pixels in software for
                        // a 40 column display. This eliminates the gap
                        // between adjacent characters that seems to be a
                        // bug in the EUSART when run at BRG=1 (Tcy/2).
                        // it costs us 512 bytes of RAM for a loopup table
                        // we can't use ROM because the TBLRD instruction
                        // takes two extra clock cycles.
                        

/**************************************************************************/

#ifdef CRYSTAL28
   #use delay(clock=28636360)
   #define SINGLE40     // we do 40 columns differently.
#else
   #define USEPLL
#endif

#ifdef CRYSTAL14
   #use     delay(clock=57272720)
#endif

#ifdef CRYSTAL13
   #use  delay(clock=54000000)
#endif

#ifdef CRYSTAL16
#use  delay(clock=64000000)
#endif


#ifdef USEPLL
   #fuses   HSPLL,NOWDT,NOPROTECT//,PUT,NOLVP
#else
   #fuses   HS,NOWDT,NOPROTECT//,PUT,NOLVP
#endif

//#include <string.h>
//#include <stdio.h>
#include "romfont.c"

#define  SYNC_BIT          2
#define  SYNC_PIN          PIN_C2      // pin 13
#define  CLOCK_PIN         PIN_C6      // pin 17
#define  PIXEL_PIN         PIN_C7      // pin 18
#define  SOUND_PIN         PIN_C1
#ifdef KCPU
#define  LED_PIN           PIN_A5
#else // JCPU
#define  LED_PIN           PIN_A3
#endif

const char copyright[]="Copyright (C) 2010 Erik C. Quackenbush, Inc.\r\nNon-commercial distribution permitted\r\nVERSION 1.1";

#ifdef DOUBLE40
   #define CONSOLECOLS   40
#else
   #ifdef SINGLE40
   #define CONSOLECOLS 40
   #else
   #define CONSOLECOLS   80
   #endif
#endif
#define CONSOLEROWS   25
#define CONSOLERAM   (CONSOLEROWS*CONSOLECOLS+2) //2082  // why waste 48 bytes of RAM at the end?
#define CONSOLELAST  (CONSOLECOLS*(CONSOLEROWS-1) )
                           // so don't change it.


// These definitions depend upon the oscillator frequency.
// Note that while we can use the chip's internal 16mhz oscillator it is not
// stable. the video signal it generates wiggles around a lot. 
// Use a crystal.

#ifdef CRYSTAL28
#define  HLINEPERIOD    113         // period of timer 2 which is pixels per hline divided by 4.
#define  HALFLINE       40         // during VSYNC we emit two pulses per line. this time between them in 4 pixel units
#define  HSyncHChars    4           // duration of HSYNC pulse in 4 pixel units
#define  VSyncHChars    2           // duration of VSYNC pulse in 4 pixel units
#define  HBackPorch     9          // horizontal backporch in 4 pixel units
#endif

#ifdef CRYSTAL14
#define  HLINEPERIOD    227         // period of timer 2 which is pixels per hline divided by 4.
#define  HALFLINE       102         // during VSYNC we emit two pulses per line. this time between them in 4 pixel units
#define  HSyncHChars    8           // duration of HSYNC pulse in 4 pixel units
#define  VSyncHChars    4           // duration of VSYNC pulse in 4 pixel units
   #ifdef DOUBLE40
   #define  HBackPorch     20          // horizontal backporch in 4 pixel units
   #else
   #define  HBackPorch     30
   #endif
#endif                              // change the backporch to adjust the
                                    // horizontal (overscan) position.
#ifdef CRYSTAL13
#define  HLINEPERIOD    215
#define  HALFLINE       96
#define  HSyncHChars    7   
#define  VSyncHChars    4     
#define  HBackPorch     16
#endif

#ifdef CRYSTAL16
#define  HLINEPERIOD    254
#define  HALFLINE       115
#define  HSyncHChars    8  
#define  VSyncHChars    4     
#define  HBackPorch     27    
#endif

#define  VSYNCLINE      220            // change this to adjust the top margin (overscan area)
#define  ACTIVE         CONSOLEROWS*8  // 200 active lines.
#define  FIELDLINES     262            // start at 1, 263=0 We're off by a half line but we're not interlaced.
#define  OVERSCANLINES  10

//
// EUSART
// we're using the EUSART as a high speed shift register to 
// output pixels. Master synchronous transmit mode.
//
#include "registers.c"

/******************** GLOBAL VARIABLES *************************/

unsigned char console[CONSOLERAM];
#locate console=0x100      // this address is hard coded because
                           // it must be at the start of a page (256).
                           // You could change it to 0x200, 0x300, etc.
                           // but not 0x180, 0x317, etc.

int conX=0,conY=0;     // position of cursor
#define CURSOR (32+128) // reverse video space cursor



int seconds=0,minutes=0,hours=0,fields=0,blankscreen=0,even=0;
unsigned int32 ticks=0; // number of horizontal video lines since powerup

#include "ps2.c"      // PS/2 keyboard support coming soon

// this is our offset into console memory

#ifdef DOUBLE40

unsigned char Dubs[256];
unsigned char Dubs2[256];
#locate Dubs=0x500
#locate Dubs2=0x600

long DubW=0x500; // just past the end of the 40 column console RAM
int DubL,DubH;
#locate DubW=0x56
#locate DubH=DubW+1
#locate DubL=DubW

long Dub2W=0x600; // one page past the end of the 40 column console RAM
int Dub2L,Dub2H;
#locate Dub2W=0x58
#locate Dub2H=Dub2W+1
#locate Dub2L=Dub2W

#endif


/*************** end of globals ***********************/

/*************** start of video interrupt code ********/

#INLINE
void UpdateClock(void)
{
   if(fields==60)
   {
      fields=0;
      seconds++;
      if(seconds==60)
      {
         seconds=0;
         minutes++;
         if(minutes==60)
         {
            minutes=0;
            hours++;
         }
      }
   }
}

unsigned int safety[0x15]; // this stores our registers during ISR
#locate safety=0x004

#INT_GLOBAL
void HScan(void)
{
   static int hloop,hcount;
   static long hline=0;       // this holds our current scanline
   static int hlinel,hlineh;
   static long charW=console;// this is our pointer into console RAM
   static int charL,charH;
   static int syncpos=0;      // positive sync pulse
   static int syncshort=0;    // two short sync pulses instead of one long one
   static int syncneg=0;
   static int activeline=0;
   #locate hline=0x50
   #locate hlineh=hline+1
   #locate hlinel=hline
   #locate charW=0x52
   #locate charH=charW+1
   #locate charL=charW
// static variables we preserve between interrupts (no need to make them global)
#asm
      // we have not enabled high priority interrupts so we don't need to 
      // pad out interrupt vector with NOPs to get us to 0x018
      
      // we rely on the shadow status,w,&BSR registers to keep track of our
      // state. we don't save them manually

      MOVLB  0x00             // set Bank zero
      BTFSC    syncpos,0      // are we positive sync?
      BCF      LATC,SYNC_BIT  // yes, turn off the sync pin output_low(SYNC_PIN);
      MOVFF    FSR0L,0x0C     // saving the registers takes
      MOVFF    FSR0H,0x07     // 28 instructions
#ifdef DOUBLE40
      MOVFF    FSR1L,0x08     // we only use FSR0 and FSR1 in DOUBLE40 mode
      MOVFF    FSR1H,0x09     
      MOVFF    FSR2L,0x0A
      MOVFF    FSR2H,0x0B
#endif      
#ifdef SINGLE40   
      BTFSC    syncshort,0    // short sync pulse?
      BSF      LATC,SYNC_BIT  // clear the sync pin early
      MOVFF    PCLATH,0x14
      MOVFF    TABLAT,0x15
      BTFSC    syncpos,0      // are we normal sync?
      BSF      LATC,SYNC_BIT  // yes- turn on the sync pin   
#else
      MOVFF    PCLATH,0x14
      BTFSC    syncshort,0    // short sync pulse?
      BSF      LATC,SYNC_BIT  // clear the sync pin early
      MOVFF    TABLAT,0x15
#endif
      MOVFF    TBLPTRL,0x16
      MOVFF    TBLPTRH,0x17
#ifdef SAVESCRATCH
      MOVFF    0x00,0x0E // these scratch registers were used by the old switch statement
      MOVFF    0x01,0x0F // we don't need to save them now.
      MOVFF    0x02,0x10
      MOVFF    0x03,0x11
#endif      
//    MOVFF    PRODL,0x12   // we don't use the multiplier
//    MOVFF    PRODH,0x13
#ifndef SINGLE40
      BTFSC    syncpos,0      // are we normal sync?
      BSF      LATC,SYNC_BIT  // yes- turn on the sync pin
#endif // SINGLE40
EndSync:
      BTFSS    PIE1,TMR2IE    // where should this live? earlier?
      GOTO     SkipInt 
      // no actual interrupt pending? that
                              // should never happen but if it does we 
                              // just go quietly
scanout:      
      BTFSS    activeline,0
      BRA      notactiveline
backporch:
      MOVLW    HBackPorch   // back porch delay
      MOVWF    hcount
chardelay:
      NOP            // four instructions per half character
      DECFSZ   hcount
      BRA      chardelay

      MOVF   hlinel,W
      ANDLW  0x07
      BZ     topofline        // if((hlinel&0x07)!=0) 

      MOVLW  CONSOLECOLS
      SUBWF  charL,F
      MOVLW  0x00
      SUBWFB charH,F  // this is a 16 bit subtract so undercarry
      BRA    setloop    //else

topofline:
      NOP               // it takes 8 scan lines to draw a character. we subtract
      NOP               // charW to the beginning of the line each time except
      NOP               // when we're on the first line (top of char).
      NOP               // The NOPs are here to ensure the same number of cycles
      NOP               // until the first pixel whether we branch or not.

setloop:
#ifdef SINGLE40
      MOVLW    20//(CONSOLECOLS)/2    // two per loop in SINGLE40 mode
#else      
      MOVLW    40          // loops per line. we do 2 chars per loop in 80 column mode, 1 per loop in 40 column mode
#endif      
      MOVWF    hloop
      
      MOVFF    charL,FSR0L // load our offset into console character memory
      MOVFF    charH,FSR0H      
#ifdef DOUBLE40
      MOVFF    Dub2H,FSR1H
      MOVFF    DubH,FSR2H
#endif
      MOVLW    0x07
      ANDWF    hlinel,w
      ADDLW    ROMFONT/256        // assumes font starts at 0x2000, add the line offset
      MOVWF    TBLPTRH
      MOVLW    0
      MOVWF    TXREG
      BSF      TXSTA,TXEN_BIT
//      BSF      RCSTA,SPEN_BIT // turn on the shift register
overscan:
      MOVWF   TXREG
#ifdef DOUBLE40
      NOP
      NOP
      NOP
      NOP
      NOP
      NOP
      NOP
      MOVWF    TXREG
      NOP
      NOP
      NOP
      NOP
      NOP
      NOP
      NOP
      MOVWF    TXREG
      NOP
      NOP
      NOP
      NOP
      NOP
      MOVFF    POSTINC0,TBLPTRL
      MOVWF    TXREG
      NOP
//      NOP
pixels:
      TBLRD    *                   // read our font data
      MOVFF    TABLAT,FSR1L
      MOVFF    INDF2,TXREG
      DECF     hloop,F
      NOP                        // we need this NOP

      MOVFF    TABLAT,FSR2L
      MOVFF    POSTINC0,TBLPTRL // move from *FSR0++ to the Table address low byte
      MOVFF    INDF1,TXREG
      BNZ      pixels          // are we done with the line?
endpixels:
      NOP
      NOP
      NOP
      NOP
      MOVFF    INDF2,TXREG
      MOVF     POSTDEC0
      NOP
      NOP
#else
   #ifndef SINGLE40
      NOP
      NOP
      NOP
      NOP
      NOP
      NOP
      NOP
      MOVWF    TXREG
      NOP
   #endif
pixels:
      MOVFF    POSTINC0,TBLPTRL // move from *FSR0++ to the Table address low byte
      TBLRD    *                   // read our font data
//      bsf      LATC,7
//      NOP
      MOVFF    TABLAT,TXREG
      DECF     hloop,F
      NOP                        // we need this NOP
      MOVFF    POSTINC0,TBLPTRL // move from *FSR0++ to the Table address low byte
      TBLRD    *                 // read our font data
//      bcf      LATC,7
      MOVFF    TABLAT,TXREG
      BNZ      pixels
endpixels:
      NOP   // we need these in 80 column mode
      NOP
      NOP
#endif

      MOVFF    FSR0L,charL  // save our character position
      MOVFF    FSR0H,charH

      BCF      TXSTA,TXEN_BIT
//      CLRF     RCSTA       // OK, shut off the shift register now

      BRA      postvideo

//*******************************************************************
// if it's not an active line we still have to generate a back porch
// and perhaps a second sync pulse
//*******************************************************************
notactiveline:

      BTFSS    syncpos,0
      BRA      vsynccode
// do a back porch but do not emit video
topbackporch:
      MOVLW    HBackPorch   // back porch delay
      MOVWF    hcount
topchardelay:
      NOP            // four instructions per half character
      DECFSZ   hcount
      BRA      topchardelay

idletime:
      MOVLW    5        // number of instructions div 3- aligns our sync
      MOVWF    hcount
idleloop:
      DECFSZ   hcount
      BRA      idleloop

#ifdef DOUBLE40
      NOP
      NOP
      NOP
      NOP
#endif
      MOVLW    0
      BSF      TXSTA,TXEN_BIT
//      BSF      RCSTA,SPEN_BIT // turn on the shift register
      MOVWF    TXREG
      NOP
      NOP
      NOP
      NOP
      NOP
      NOP
      NOP
      BCF   TXSTA,TXEN_BIT
//      CLRF  RCSTA
      BRA   postvideo
vsynccode:

halfporch:
      MOVLW    HALFLINE // back porch delay
      MOVWF    hcount
halfdelay:
      NOP            // four instructions per half character
      DECFSZ   hcount
      BRA      halfdelay    

      BTFSS    syncpos,0
      BRA      vsyncold

positivesecond:
      BCF      LATC,SYNC_BIT  // yes, turn off the sync pin output_low(SYNC_PIN);
      MOVLW    VSyncHChars
      MOVWF    hcount
secondsyncpos:
      NOP
      DECFSZ    hcount
      BRA       secondsyncpos
      BSF      LATC,SYNC_BIT  // clear the sync pin early
      BRA      vsyncold


halfsyncstart:
      BSF      LATC,SYNC_BIT
      MOVLW VSyncHChars
      MOVWF hcount
halfsyncdelay:
      NOP            // four instructions per loop == 1/2 character at 80 columns (1 character at 40 columns)
      DECFSZ   hcount
      BRA   halfsyncdelay
      BCF      LATC,SYNC_BIT

vsyncold:

      BTFSS    syncneg,0
      BRA      postvideo

      BSF      LATC,SYNC_BIT
      MOVLW VSyncHChars
      MOVWF hcount
halfsyncnegdelay:
      NOP            // four instructions per loop == 1/2 character at 80 columns (1 character at 40 columns)
      DECFSZ   hcount
      BRA   halfsyncnegdelay
      BCF      LATC,SYNC_BIT

      BTFSS    syncshort,0
      BRA      postvideo
      MOVLW 2
      MOVWF hcount
delay4:
      NOP
      DECFSZ hcount,F
      BRA    delay4
      BSF    LATC,SYNC_BIT

postvideo:
#endasm

   hline++;

   if(hline==FIELDLINES)
   {   
      hline=0;
   }

   // here we set some flags to determine what the next video line will
   // look like. will it have active pixels? will it have negative sync?

   syncpos=1;     // normal sync 
   activeline=0;  // not active video
   syncshort=0;   // full width sync pulse
   syncneg=0;     // end with a negative sync pulse
   
   if(hline<ACTIVE)
   {
      if(blankscreen==0) activeline=1; // the next line is active video
   }
   else if(hlinel==VSYNCLINE+9-256)// we already know it's inactive so we can ignore the high byte
      {

      // the clock is wrong here. we need to add an extra scan line
      // at the beginning of the EVEN fields to avoid losing time.

         fields++;
         ticks++;
         //if(ticks%16==0) console[CONSOLERAM-CONSOLECOLS-2]^=0x80; // blink the cursor
         UpdateClock();
         syncpos=0;
      }
      else
      {
      if(hline==ACTIVE)
      {
         charW=console;// this is 0x100 at the end of each active field we reset the pointer into character memory
      }
      else if(hlinel==VSYNCLINE-256)     syncshort=1;
      else if(hlinel==VSYNCLINE+1-256)   syncshort=1;
      else if(hlinel==VSYNCLINE+2-256)   syncshort=1;
      else if(hlinel==VSYNCLINE+3-256)   { syncpos=0; syncneg=1; }
      else if(hlinel==VSYNCLINE+4-256)   { syncpos=0; syncneg=1; }
      else if(hlinel==VSYNCLINE+5-256)   { syncshort=1; syncneg=1; }
      else if(hlinel==VSYNCLINE+6-256)   syncshort=1;
      else if(hlinel==VSYNCLINE+7-256)   syncshort=1;

   }

   if(hline==ACTIVE)
   {
      if(even)
      {
         even=0;
         hline++; // skip a line on even fields
      }
      else even=1;
   }

   // restore our registers before returning
#asm
      BCF      PIR1,TMR2IF

SkipInt:

#endasm
      KBint();
#asm
      BTFSC  PIR1,TMR2IF
#ifdef SAVESCRATCH // if you use a switch() statement you need this
      MOVFF  0x0E,0x00
      MOVFF  0x0F,0x01
      MOVFF  0x10,0x02
      MOVFF  0x11,0x03
#endif      
      MOVFF  0x0C,FSR0L
      MOVFF  0x07,FSR0H
#ifdef DOUBLE40
      MOVFF  0x08,FSR1L
      MOVFF  0x09,FSR1H
      MOVFF  0x0A,FSR2L
      MOVFF  0x0B,FSR2H
#endif      
//      MOVFF  0x12,PRODL
//      MOVFF  0x13,PRODH
      MOVFF  0x14,PCLATH
      MOVFF  0x15,TABLAT
      MOVFF  0x16,TBLPTRL
      MOVFF  0x17,TBLPTRH
      RETFIE 1             // restore shadow registers

#endasm

}

/**************** end of video generation ***************************/

/************ start of console/ video terminal handling functions***/

void CursorOn()
{
   console[(long)conX+(long)conY*CONSOLECOLS]|=0x80;
}

void CursorOff()
{
   console[(long)conX+(long)conY*CONSOLECOLS]^=0x80;
}

void ClearScreen(void)
{
   long index;
   
   for(index=0;index<CONSOLERAM;index++)
   {
      console[index]=0;
   }
}

void ScrollUp(int CR)
{
   long index;

   if(ConY<CONSOLEROWS-1)
   {
      ConY++;
   }
   else
   {
      for(index=0;index<CONSOLERAM-CONSOLECOLS;index++)
      {
         console[index]=console[index+CONSOLECOLS];
      }
   
     for(index=CONSOLELAST;index<CONSOLELAST+CONSOLECOLS;index++) console[index]=32;
     
   }
     if(CR) conX=0;
}

void ScreenChar(char symbol)
{
   CursorOff();
   switch(symbol)
   {
      case 8: // backspace
         if(conX) conX--;
         break;
      case '\n':// line feed
         ConY++;
         if(ConY==CONSOLEROWS)
         {
            ScrollUp(0);// no carriage return- just a line feed
            ConY--;
         }
         break;
      case '\r': // carriage return
         conX=0;
         break;
      default:
         console[CONSOLECOLS*(long)conY+(long)conX]=symbol;
         conX++;
         if(conX>=CONSOLECOLS)
         {
            ConY++;
            if(conY>CONSOLEROWS)
            {
               conY=CONSOLEROWS;
               ScrollUp(1); 
            }
         }
   }
   CursorOn();
}

void StringWrite(char *dest,char *source) // write a string without writing the terminating NULL
{
  int index=0;
  
  while(source[index]!=0)
  {
   if(dest<CONSOLERAM) *dest++=source[index++];
  }
}

void InitConsoleRAM1(void)
{
   long index;
  
   for(index=0;index<CONSOLERAM;index+=CONSOLECOLS) // fill the screen with a test pattern
   {
                                 //123456789-123456789-12345678-123456789-123456789-123456789-123456789-123456789-
#ifdef DOUBLE40
                              // 123456789-123456xx789-123456789-123456789-
      sprintf(&console[index],"%2ld THIS IS LINE %2ld          30        40",index/CONSOLECOLS,index/CONSOLECOLS);
//      sprintf(safetemp,"%2ld THIS IS LINE %2ld          30        40",index/CONSOLECOLS,index/CONSOLECOLS);
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
void main( void )
{
   char *right;
   right=copyright; 

#ifdef USEPLL
   osctune|=PLLEN; // crank it up to 4X PLL
#endif
   output_high(LED_PIN);

   delay_ms(50);
   output_low(LED_PIN);
   delay_ms(50);
   output_high(LED_PIN);
   delay_ms(50);
   output_low(LED_PIN);
   delay_ms(50);
   output_high(LED_PIN);

// Beep();

   InitSystem();
   InitKeyboard();
//   TimeDisplay();
//   ScrollUp(1);
   TypeWriter();
//   ScrollOff();

   for(;;) ; // just wait
}

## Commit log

2025-08-11 schematic has major components placed and most pins named
    [Project68.kicad_pcb, Project68.kicad_sch]
2025-08-11 wired I/O ports
    [Project68.kicad_sch]
2025-08-12 grounded NC pin on SRAM
2025-08-12 added status LED
    [Project68.kicad_sch]
2025-08-13 level shifters & CH340
    [Project68.kicad_sch]
2025-08-13 moved files around
    [Project68.kicad_pcb, Project68.kicad_sch]
2025-08-25 began autorouting
    [Project68.kicad_pcb, Project68.kicad_sch]
2025-09-03 almost ready for production
    [Project68-B_Cu.gbl, Project68-B_Mask.gbs, Project68-B_Paste.gbp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]
2025-09-10 added support for 4 bit SD card access
    [Project68.kicad_pcb, Project68.kicad_sch]
2025-09-12 added daughter card dual serial
    [DAUGHTER.kicad_pcb, DAUGHTER.kicad_sch]
